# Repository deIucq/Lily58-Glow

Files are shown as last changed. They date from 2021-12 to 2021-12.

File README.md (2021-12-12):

# Lily58 - χ
ビルドガイドは[こちら](https://github.com/deIucq/Lily58-X/blob/master/buildguide.md)

BuildGuide is [here](https://github.com/deIucq/Lily58-X/blob/master/buildguide.md)

Lily58-χ(カイ)はLily58からforkされた[Lily58-glow](https://github.com/qtkb/Lily58-Glow)に以下の変更を加えたものです。
検索性向上のために，ここ以外ではLily58-Xと表記します。

- RGBLEDのpad配置をSK6812mini-e用に変更
- Underglow用LEDの場所・数を変更
- BLE Micro Proのインジケータ用にLEDを追加
- トラックパッド用のピンヘッダ・ネジ穴を追加
- 縁を覆うようなケースを追加
- I2Cと単線シリアルをスイッチできるようにジャンパーを追加
- TRRSジャックのピンアサインを変更(moduloと同様のピンアサイン)

Lily58-χ(chi) is a forked version of [Lily58-glow](https://github.com/qtkb/Lily58-Glow) from Lily58 with the following changes.

- Change RGB LED pad to SK6812mini-e's one.
- Change place and number of LEDs for underglow.
- Add LED for BLE Micro Pro's indicator.
- Add new Pinheader for trackpad modules.
- Add case that can cover edge.
- Add jumber for switching I2C and Serial
- Change TRRS pin assign

このプロジェクトは開発中です。PCBの設計にミスがある可能性があります。
This project is still in progress. There may be some mistakes in PCB design.

PCB view

# Parts

| Part Name | Quantity |
| --- | --- |
| PCB | 2 |
| Top Case,Mid Case,Bottom Case(t2 acrylic) | 2 |
| Pro Micro or BLE Micro Pro | 2 |
| Choc Key Switch | 58 |
| Keycap | 58 |
| SK6812-MINI-E | 58 |
| OLED | 2 |
| Diode 1N4148W | 58 |
| Tact switch | 2 |
| TRRS jack (option for Pro Micro) | 2 |
| TRRS cable (opton for Pro Micro) | 1 |
| M2 screw 10mm | 10 |
| M2 Nut | 20 |
| M2 spacer 10mm | 4 |
| M2 screw 4mm | 8 |
| Urethane cushion | 10 |
| Low profile pin header(1×4 & 1×6) | 2 |
| [option] RKJXY1000006 trackpad with DIP convertPCB | 1 |
| [option] 1608 LED | 1 |
| [option] Constant current diode or resistor | 1 |

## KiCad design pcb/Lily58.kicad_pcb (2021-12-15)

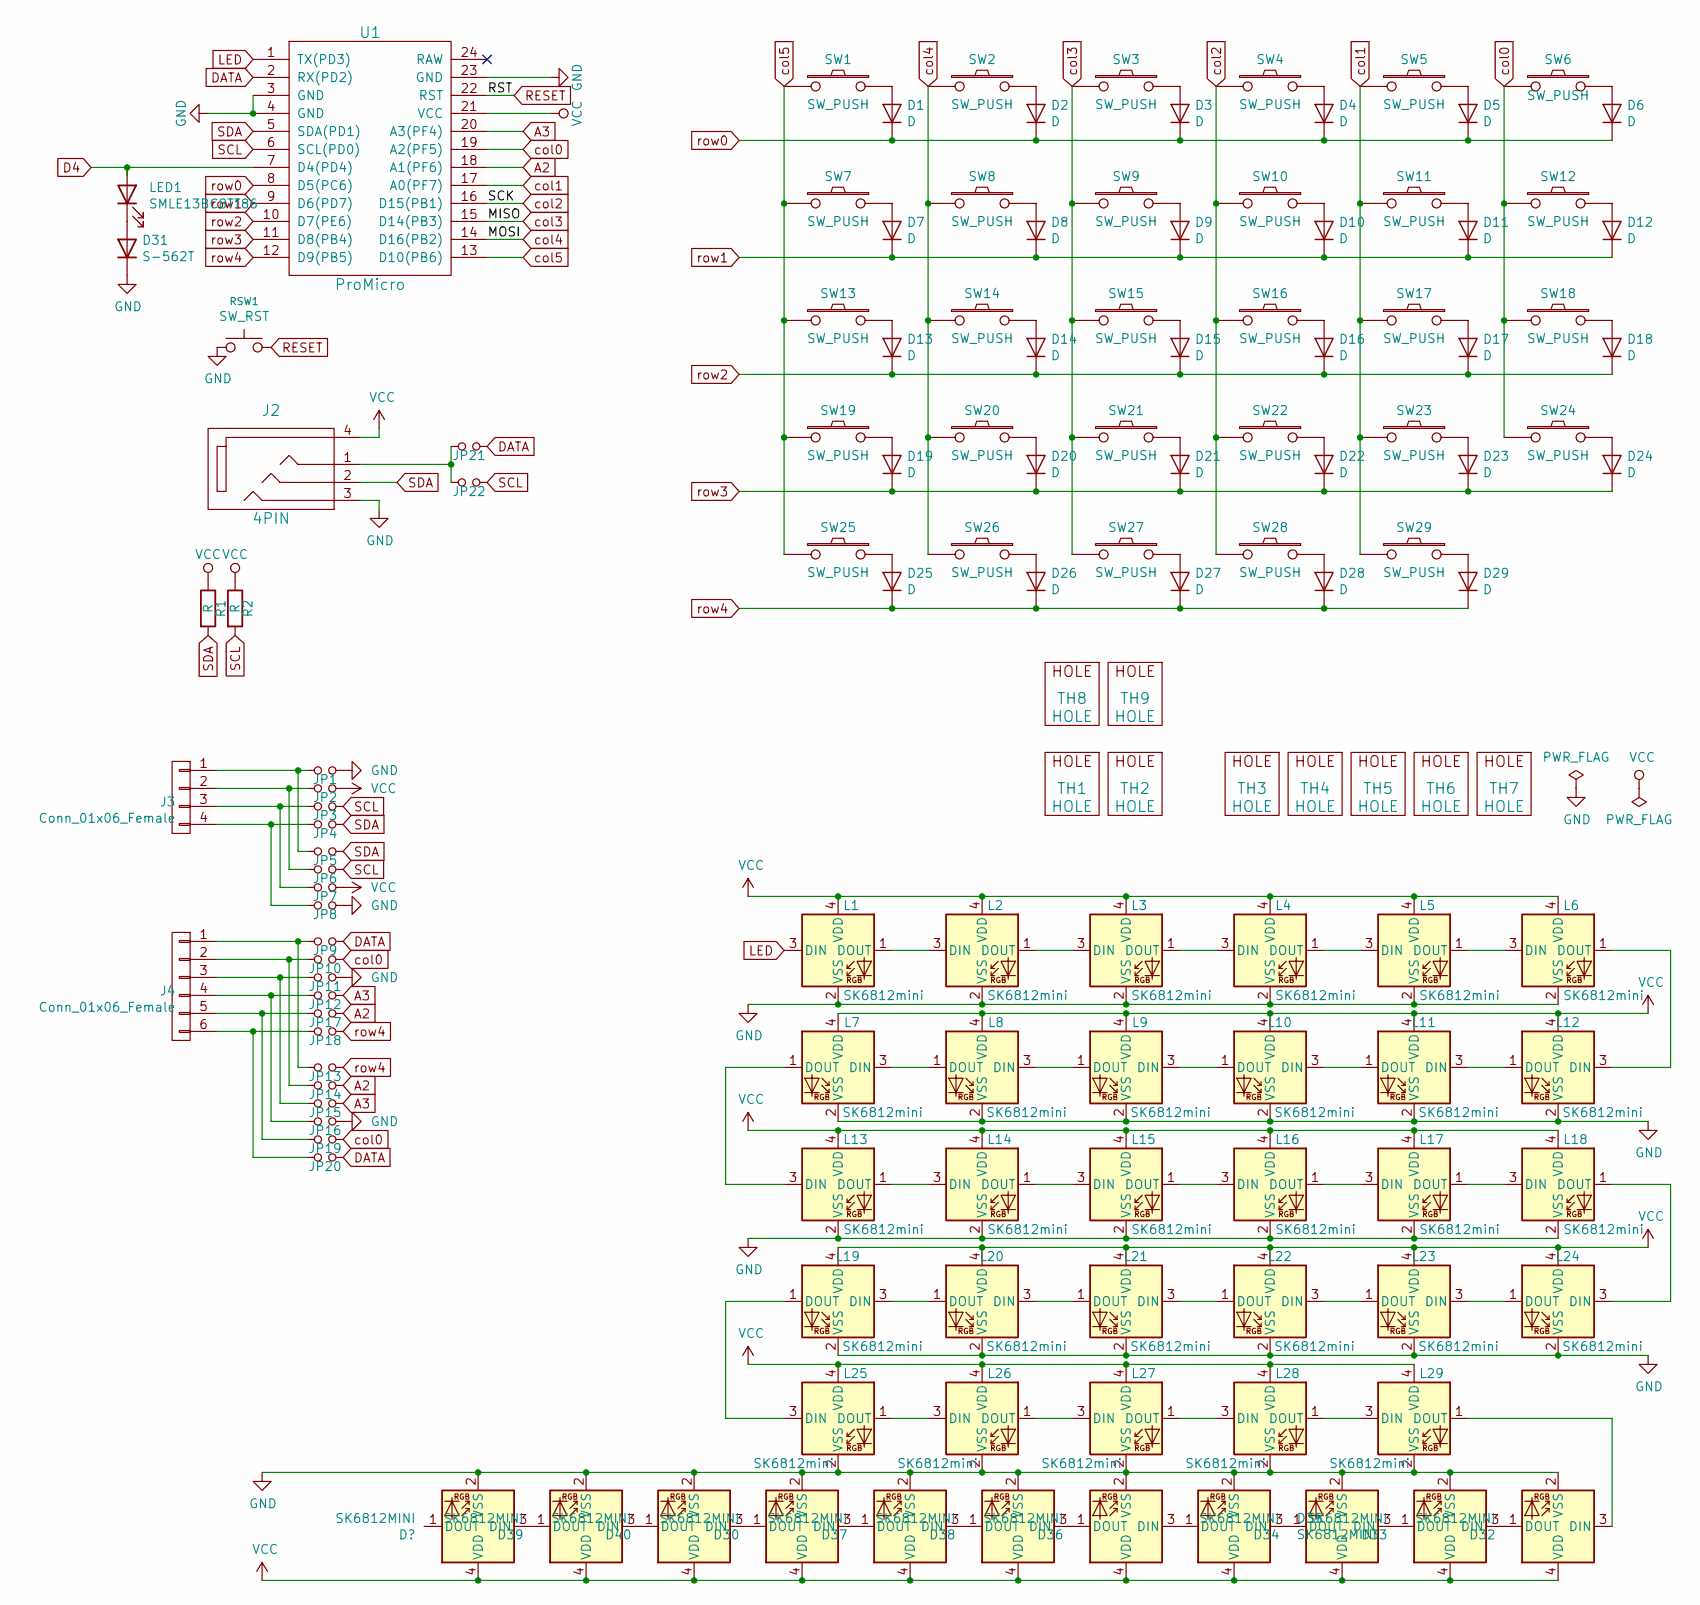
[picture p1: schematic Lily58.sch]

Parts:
D1, D2, D3, D4, D5, D6, D7, D8, D9, D10, D11, D12, D13, D14, D15, D16, D17, D18, D19, D20, D21, D22, D23, D24, D25, D26, D27, D28, D29: D; Diode_SOD123
D30, D32, D33, D34, D35, D36, D37, D38, D39, D40: SK6812MINI; SK6812MINI_underglow_rev
D31: S-562T; D_1206_3216Metric_Pad1.42x1.75mm_HandSolder
J2: 4PIN; MJ-4PP-9
J3: Conn_01x06_Female; OLED_4Pin
J4: Conn_01x06_Female; OLED_6Pin
JP1, JP2, JP3, JP4, JP5, JP6, JP7, JP8, JP9, JP10, JP11, JP12, JP13, JP14, JP15, JP16, JP17, JP18, JP19, JP20: Jumper_NO_Small; Jumper
JP21: 1S; Jumper
JP22: I2C; Jumper
L1, L2, L3, L4, L5, L6, L7, L8, L9, L10, L11, L12, L13, L14, L15, L16, L17, L18, L19, L20, L21, L22, L23, L24, L25, L26, L27, L28, L29: SK6812mini; SK6812MINI_rev
LED1: SMLE13BC8TT86; LED_0603_1608Metric_Pad1.05x0.95mm_HandSolder
R1, R2: R; RESISTOR_mini
RSW1: SW_RST; TACT_SWITCH_TVBP06
SW1, SW2, SW3, SW4, SW5, SW6, SW7, SW8, SW9, SW10, SW11, SW12, SW13, SW14, SW15, SW16, SW17, SW18, SW19, SW20, SW21, SW22, SW23, SW24, SW25, SW27, SW28, SW29: SW_PUSH; MX_PG1350_FLIP_HOLES_18mm
SW26: SW_PUSH; MX_PG1350_FLIP_HOLES_27mm
TH1, TH2, TH8, TH9: HOLE; HOLE_M2
TH3, TH4, TH5, TH6, TH7: HOLE; HOLE_M2_TH
U1: ProMicro; ProMicro_rev2

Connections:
A2: JP14.2, JP17.2, U1.18 (A1(PF6))
A3: JP12.2, JP15.2, U1.20 (A3(PF4))
D4: LED1.2 (A), U1.7 (D4(PD4))
DATA: JP9.2, JP20.2, JP21.2, U1.2 (RX(PD2))
GND: D30.2 (VSS), D31.1 (K), D32.2 (VSS), D33.2 (VSS), D34.2 (VSS), D35.2 (VSS), D36.2 (VSS), D37.2 (VSS), D38.2 (VSS), D39.2 (VSS), D40.2 (VSS), J2.3, JP1.2, JP8.2, JP11.2, JP16.2, L1.2 (VSS), L2.2 (VSS), L3.2 (VSS), L4.2 (VSS), L5.2 (VSS), L6.2 (VSS), L7.2 (VSS), L8.2 (VSS), L9.2 (VSS), L10.2 (VSS), L11.2 (VSS), L12.2 (VSS), L13.2 (VSS), L14.2 (VSS), L15.2 (VSS), L16.2 (VSS), L17.2 (VSS), L18.2 (VSS), L19.2 (VSS), L20.2 (VSS), L21.2 (VSS), L22.2 (VSS), L23.2 (VSS), L24.2 (VSS), L25.2 (VSS), L26.2 (VSS), L27.2 (VSS), L28.2 (VSS), L29.2 (VSS), RSW1.1, U1.3 (GND), U1.4 (GND), U1.23 (GND); also elsewhere on the board
LED: L1.3 (DIN), U1.1 (TX(PD3))
unnamed: D1.2 (A), SW1.2
unnamed: D2.2 (A), SW2.2
unnamed: D3.2 (A), SW3.2
unnamed: D4.2 (A), SW4.2
unnamed: D5.2 (A), SW5.2
unnamed: D6.2 (A), SW6.2
unnamed: D7.2 (A), SW7.2
unnamed: D8.2 (A), SW8.2
unnamed: D9.2 (A), SW9.2
unnamed: D10.2 (A), SW10.2
unnamed: D11.2 (A), SW11.2
unnamed: D12.2 (A), SW12.2
unnamed: D13.2 (A), SW13.2
unnamed: D14.2 (A), SW14.2
unnamed: D15.2 (A), SW15.2
unnamed: D16.2 (A), SW16.2
unnamed: D17.2 (A), SW17.2
unnamed: D18.2 (A), SW18.2
unnamed: D19.2 (A), SW19.2
unnamed: D20.2 (A), SW20.2
unnamed: D21.2 (A), SW21.2
unnamed: D22.2 (A), SW22.2
unnamed: D23.2 (A), SW23.2
unnamed: D24.2 (A), SW24.2
unnamed: D25.2 (A), SW25.2
unnamed: D26.2 (A), SW26.2
unnamed: D27.2 (A), SW27.2
unnamed: D28.2 (A), SW28.2
unnamed: D29.2 (A), SW29.2
unnamed: D30.1 (DOUT), D40.3 (DIN)
unnamed: D30.3 (DIN), D37.1 (DOUT)
unnamed: D31.2 (A), LED1.1 (K)
unnamed: D32.1 (DOUT), D33.3 (DIN)
unnamed: D32.3 (DIN), L29.1 (DOUT)
unnamed: D33.1 (DOUT), D34.3 (DIN)
unnamed: D34.1 (DOUT), D35.3 (DIN)
unnamed: D35.1 (DOUT), D36.3 (DIN)
unnamed: D36.1 (DOUT), D38.3 (DIN)
unnamed: D37.3 (DIN), D38.1 (DOUT)
unnamed 45: D39.1 (DOUT); also elsewhere on the board
unnamed: D39.3 (DIN), D40.1 (DOUT)
unnamed: J2.1, JP21.1, JP22.1
unnamed: J3.1, JP1.1, JP5.1
unnamed: J3.2, JP2.1, JP6.1
unnamed: J3.3, JP3.1, JP7.1
unnamed: J3.4, JP4.1, JP8.1
unnamed: J4.1, JP9.1, JP13.1
unnamed: J4.2, JP10.1, JP14.1
unnamed: J4.3, JP11.1, JP15.1
unnamed: J4.4, JP12.1, JP16.1
unnamed: J4.5, JP17.1, JP19.1
unnamed: J4.6, JP18.1, JP20.1
unnamed: L1.1 (DOUT), L2.3 (DIN)
unnamed: L2.1 (DOUT), L3.3 (DIN)
unnamed: L3.1 (DOUT), L4.3 (DIN)
unnamed: L4.1 (DOUT), L5.3 (DIN)
unnamed: L5.1 (DOUT), L6.3 (DIN)
unnamed: L7.3 (DIN), L8.1 (DOUT)
unnamed: L8.3 (DIN), L9.1 (DOUT)
unnamed: L9.3 (DIN), L10.1 (DOUT)
unnamed: L10.3 (DIN), L11.1 (DOUT)
unnamed: L11.3 (DIN), L12.1 (DOUT)
unnamed: L6.1 (DOUT), L12.3 (DIN)
unnamed: L13.1 (DOUT), L14.3 (DIN)
unnamed: L7.1 (DOUT), L13.3 (DIN)
unnamed: L14.1 (DOUT), L15.3 (DIN)
unnamed: L15.1 (DOUT), L16.3 (DIN)
unnamed: L16.1 (DOUT), L17.3 (DIN)
unnamed: L17.1 (DOUT), L18.3 (DIN)
unnamed: L18.1 (DOUT), L24.3 (DIN)
unnamed: L19.1 (DOUT), L25.3 (DIN)
unnamed: L19.3 (DIN), L20.1 (DOUT)
unnamed: L20.3 (DIN), L21.1 (DOUT)
unnamed: L21.3 (DIN), L22.1 (DOUT)
unnamed: L22.3 (DIN), L23.1 (DOUT)
unnamed: L23.3 (DIN), L24.1 (DOUT)
unnamed: L25.1 (DOUT), L26.3 (DIN)
unnamed: L26.1 (DOUT), L27.3 (DIN)
unnamed: L27.1 (DOUT), L28.3 (DIN)
unnamed: L28.1 (DOUT), L29.3 (DIN)
RESET: RSW1.2, U1.22 (RST)
SCL: JP3.2, JP6.2, JP22.2, R2.2, U1.6 (SCL(PD0))
SDA: J2.2, JP4.2, JP5.2, R1.2, U1.5 (SDA(PD1))
VCC: D30.4 (VDD), D32.4 (VDD), D33.4 (VDD), D34.4 (VDD), D35.4 (VDD), D36.4 (VDD), D37.4 (VDD), D38.4 (VDD), D39.4 (VDD), D40.4 (VDD), J2.4, JP2.2, JP7.2, L1.4 (VDD), L2.4 (VDD), L3.4 (VDD), L4.4 (VDD), L5.4 (VDD), L6.4 (VDD), L7.4 (VDD), L8.4 (VDD), L9.4 (VDD), L10.4 (VDD), L11.4 (VDD), L12.4 (VDD), L13.4 (VDD), L14.4 (VDD), L15.4 (VDD), L16.4 (VDD), L17.4 (VDD), L18.4 (VDD), L19.4 (VDD), L20.4 (VDD), L21.4 (VDD), L22.4 (VDD), L23.4 (VDD), L24.4 (VDD), L25.4 (VDD), L26.4 (VDD), L27.4 (VDD), L28.4 (VDD), L29.4 (VDD), R1.1, R2.1, U1.21 (VCC); also elsewhere on the board
col0: JP10.2, JP19.2, SW6.1, SW12.1, SW18.1, SW24.1, U1.19 (A2(PF5))
col1: SW5.1, SW11.1, SW17.1, SW23.1, SW29.1, U1.17 (A0(PF7))
col2: SW4.1, SW10.1, SW16.1, SW22.1, SW28.1, U1.16 (D15(PB1))
col3: SW3.1, SW9.1, SW15.1, SW21.1, SW27.1, U1.15 (D14(PB3))
col4: SW2.1, SW8.1, SW14.1, SW20.1, SW26.1, U1.14 (D16(PB2))
col5: SW1.1, SW7.1, SW13.1, SW19.1, SW25.1, U1.13 (D10(PB6))
row0: D1.1 (K), D2.1 (K), D3.1 (K), D4.1 (K), D5.1 (K), D6.1 (K), U1.8 (D5(PC6))
row1: D7.1 (K), D8.1 (K), D9.1 (K), D10.1 (K), D11.1 (K), D12.1 (K), U1.9 (D6(PD7))
row2: D13.1 (K), D14.1 (K), D15.1 (K), D16.1 (K), D17.1 (K), D18.1 (K), U1.10 (D7(PE6))
row3: D19.1 (K), D20.1 (K), D21.1 (K), D22.1 (K), D23.1 (K), D24.1 (K), U1.11 (D8(PB4))
row4: D25.1 (K), D26.1 (K), D27.1 (K), D28.1 (K), D29.1 (K), JP13.2, JP18.2, U1.12 (D9(PB5))

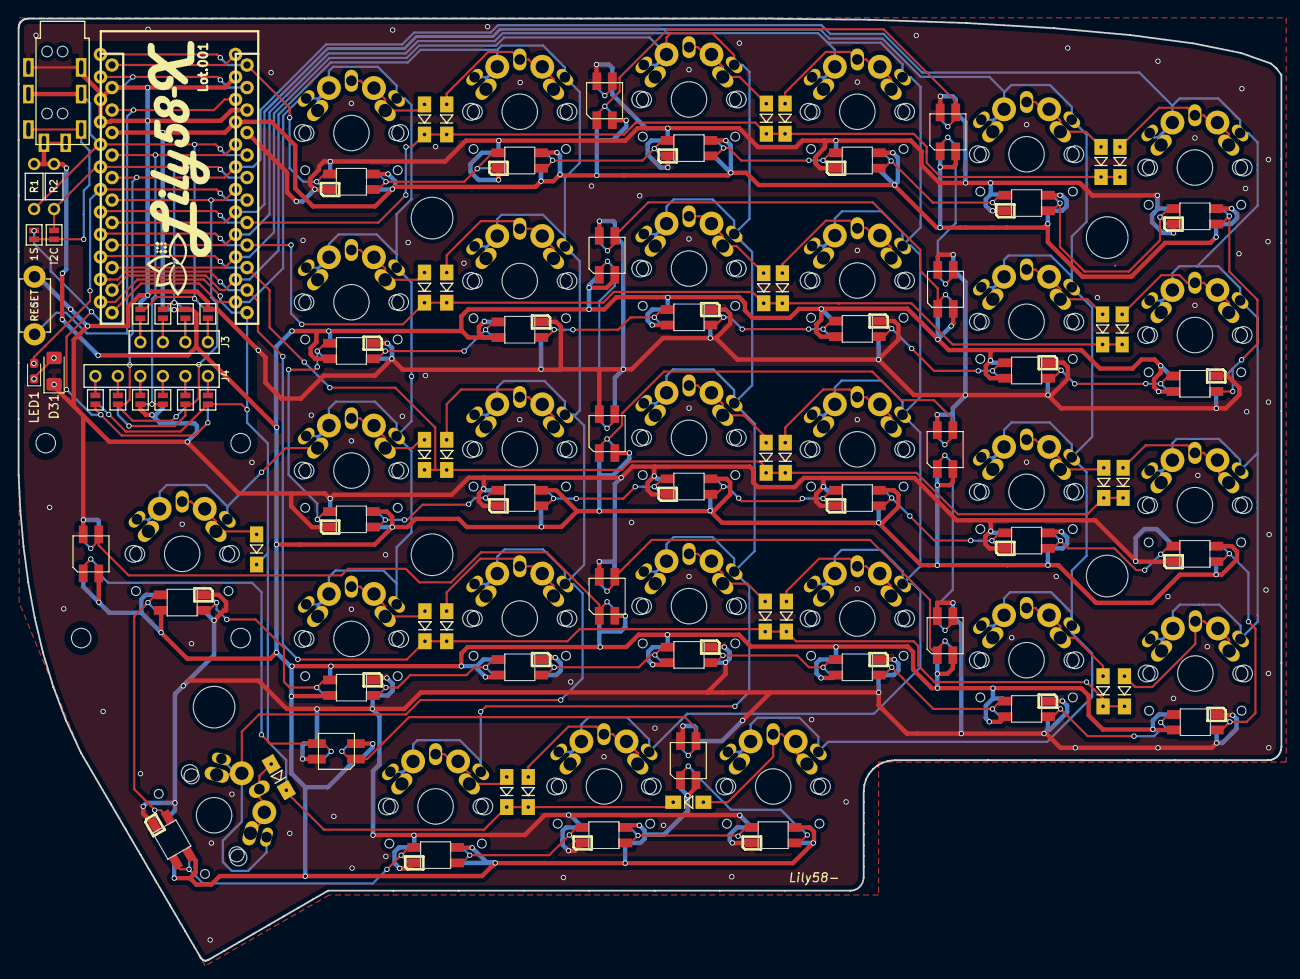
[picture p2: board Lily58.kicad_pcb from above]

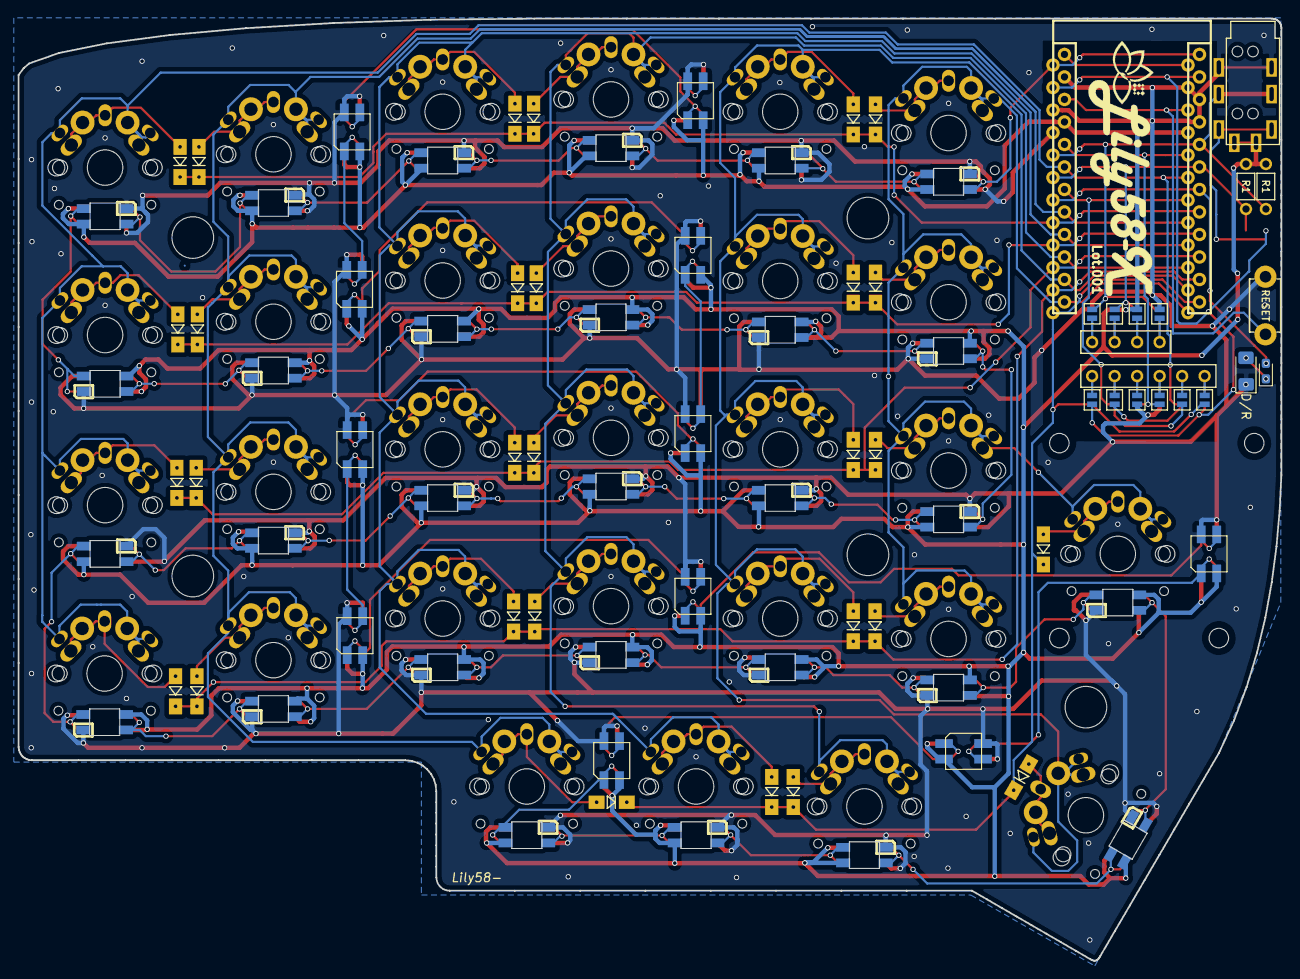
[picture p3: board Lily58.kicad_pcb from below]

Board: 2 copper layers, 142.5 x 106.3 mm, 138 parts (38 on the bottom side), 101 nets.

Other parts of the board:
D41: SK6812MINI; SK6812MINI_underglow_rev

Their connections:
GND: D41.2; also elsewhere on the board
unnamed 45: D41.3; also elsewhere on the board
VCC: D41.4; also elsewhere on the board

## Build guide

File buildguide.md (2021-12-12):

# Lily58-X ビルドガイド

## パーツ

| パーツ名 | 個数 | 備考 |
| --- | ---- | --- |
| Lily58-X キット | 1 | PCB，ケース，RGBLED，ダイオード，ピンソケット，タクトスイッチ，TRRSジャック，ネジ類，ゴム足が付属しています |
| Pro Micro or BLE Micro Pro | 2 | BLE Micro Proは複雑なので初めての方はPro Microを推奨します。<br>また，コネクタが破損したときなどにボードを交換できるようにコンスルーの使用を推奨します。 |
| キースイッチ | 58 | ChocでもMXでも可。ただし，MXの場合はミッドプレートとトッププレートの間に隙間が空き，完全に縁が埋まりません。ChocのためのケースなのでChocを推奨します。 |
| キーキャップ | 58 | ネジの突き出しがあるので，スイッチ取り付け部より下に張り出すキーキャップ(例:kailh公式transparentキーキャップ)を使うとネジに少し当たります。Chocolate形のみ大丈夫であることを確認しています。 |
| TRRSケーブル | 1 | 単線シリアル(後述)にする場合はTRSケーブルでも可 |
| USBケーブル | 1 | 使うボードに合わせて選んでください。(Pro Microの場合はMicro USB，BLE Micro Proの場合はType C) |
| [Option] Underglow用 SK6812MINI | 5 | はんだ付けが難しい・スペース的にギリギリなことからオプションとしています。 |
| [Option] 1608サイズLED・定電流ダイオード | 1 | BLE Micro Proのインジケータ用のLEDを取り付けることができます。パーツが小さく，はんだ付けが難しいので上級者向けかもしれません。<br />[LED](https://akizukidenshi.com/catalog/g/gI-15109/)[定電流ダイオード](https://akizukidenshi.com/catalog/g/gI-06282/) |
| [Option] トラックパッド | 0~1  | トラックパッドを使う場合は，キースイッチ・キーキャップは57個となります。 |
| [Option] OLED | 0~2  | BLE Micro Proとはバッテリーのスペースの問題で共存できません。 |

## 工具

- ドライバー
- はんだ付けに使う道具類
  - はんだごて
  - はんだ
  - ピンセット(推奨)
  - ハンダ吸い取り線またはハンダ吸い取り器(失敗したときの修正に必要)
  - マスキングテープ(あると良い)
  - フラックス(あると良い。はんだ付けする前に金属部分に塗ります。)

## 

## 

## オプション

このキーボードにはいくつかのオプションがあります。排他的であるものが多いので注意してください。

- ジョイスティック
  秋月のRKJXY1000006 DIP化キットを直差ししてポインティングデバイス(=マウス)として利用することができます。
  https://akizukidenshi.com/catalog/g/gK-15425/
- 左右の通信方式
  I2Cと単線シリアルの2種類から選べます。
  I2Cはジョイスティックを使う場合・BLE Micro Proと組み合わせて半無線化するモジュールであるLPME-IOを使う場合に選択してください。
  単線シリアルの場合は，TRRSではなくTRSケーブルで通信できるというメリットがあります。

## 手順

0. [基板の左右を決める](#基板の左右を決める)
1. [ダイオード・RGBLED取り付け](#ダイオード・RGBLED取り付け)
2. [インジケータ用ダイオード・LED取り付け](#インジケータ用ダイオード・LED取り付け)
3. [TRRSジャック・リセットスイッチ・ピンソケット取り付け](#TRRSジャック・リセットスイッチ・ピンソケット取り付け)
4. [ジャンパ](#ジャンパ)
5. [Pro Micro / BLE Micro Pro取り付け](#Pro Micro / BLE Micro Pro取り付け)
6. [トッププレートとキースイッチ取り付け](#トッププレートとキースイッチ取り付け)
7. [基板洗浄](#基板洗浄])
8. [トラックパッド取り付け](#トラックパッド取り付け)
9. [スペーサー取り付け](#スペーサー取り付け)
10. [OLED取り付け](#OLED取り付け)
11. [ミッドプレート・ボトムプレート・ゴム足取り付け](#ミッドプレート・ボトムプレート・ゴム足取り付け)
10. [ファームウェア書き込み](#ファームウェア書き込み)

## 基板の左右を決める

Lily58-Xの基板はリバーシブルになっています。つまり，右側の基板を二枚作ってしまったというようなミスが起こる可能性があるので，まずはどちらの基板を左/右にするか決めて，表面がどちらなのかそれぞれ覚えておきましょう。(不安な場合は，マスキングテープなどで印を付けておくことをおすすめします。)

## ダイオード・RGBLED取り付け

ダイオードとLEDは基板の**裏面**に取り付けます。

ダイオードは線が引いてあるほうがカソードです。基板上の矢印のようなダイオードの記号の向きに合わせてはんだ付けします。
表面実装の部品は先にパッドを1つだけ予備ハンダして，それを使って固定してから他のパッドをはんだ付けするとやりやすいです。

LEDはLED側は端が欠けている様な形をしているピン，基板側は黒い線で囲われているパッドがGNDになっています。それぞれ合わせてはんだ付けします。
LEDの裏表は表面の方が光るようにします。(GNDをあわせていれば間違えようがないですが)間違えないようにしましょう。

## インジケータ用ダイオード・LED取り付け

基本的にBLE Pro Micro向けなのでPro Microのみを用いる場合は飛ばしても良いです。

表面実装のダイオードとLEDを取り付けます。
極性は基板上で黒い線が引かれている側がカソードで，ダイオードは線が引かれている方，LEDは裏面を見て矢印が向いている方がカソードです。それぞれ合わせてはんだ付けします。

## TRRSジャック・リセットスイッチ・ピンソケット取り付け

TRRSジャック，リセットスイッチ，ピンヘッダは表側から挿してマスキングテープなどで仮固定し，裏面からはんだ付けします。

## ジャンパ

ピンヘッダ近くの**表側**のパッドをジャンパさせてください。
また，左右の通信方式に合わせてパッドをジャンパさせてください。(これは片面にしか有りません。)

## Pro Micro / BLE Micro Pro取り付け

取り付け位置はそれぞれ表面から見て黒い枠で囲まれている部分に表面から取り付けます。

Pro Micro，BLE Micro Pro共に，**マイコンなどの部品が載っている側が下になるように**取り付けます。
Arduino Nanoなどとは違う方向なので注意してください。

### コンスルーを使う場合

Helixの[ビルドガイド](https://github.com/MakotoKurauchi/helix/blob/master/Doc/buildguide_jp.md#pro-micro)を参考にしてはんだ付けを行います。

Pro Microの場合はPro Micro側のみはんだ付けを行い、PCB側ははんだ付けしません。
BLE Micro Proの場合はどちらもはんだ付けの必要はありません。

はんだ付けが終わった後は浮きが無いようにしっかりと差し込みます。

### 通常のピンヘッダを使う場合

先にピンヘッダを差し込み，その上にPro Microを載せてはんだ付けします。
その後，マスキングテープなどで仮固定し，裏面からピンヘッダをはんだ付けします。

## トッププレートとキースイッチ取り付け

トッププレートはジョイスティックが使えるものと使えないものがあります。**どちらにジョイスティックを取り付けるか確認**した後，

トッププレートの4つ角にキースイッチを取り付けて

- キースイッチがPCBから浮いていないこと
- ピンが曲がっていないこと
をよく確認してはんだ付けします。

その後，トッププレートに残りのスイッチを取り付けてピンがしっかり通っていることを確認してはんだ付けします。
スイッチのピンの足が曲がってしまった際は，手でもとに戻してください。

## 基板洗浄

ここではんだ付けは終了です。お疲れさまでした。
はんだ付けをした後，基板にフラックスによる茶色っぽい色の汚れが付着していると思います。放置しても基本的には問題ないと思いますが，見栄えがよろしくないので可能であればエタノールやIPAといったアルコール系の溶剤と綿棒などを使ってフラックスの洗浄をしましょう。

## ジョイスティック取り付け

ジョイスティックを取り付ける場合はこの段階で取り付けます。
ジョイスティックと基板のネジ穴を合わせてネジで固定します。

## スペーサー取り付け

保護パネル用のスペーサーを取り付けます

## OLED取り付け

OLEDを取り付ける場合はこの段階で取り付けます。

## ミッドプレート・ボトムプレート・ゴム足取り付け

ミッドプレートとボトムプレートの位置を合わせてネジ止めして裏面にゴム足を取り付けます。

## ファームウェア書き込み

### Pro Microの場合

- VIAを使う

  1. Githubにあるhexファイルとjsonファイルをダウンロード

  2. Pro Micro Web UpdaterもしくはQMK ToolBoxを使ってhexファイルを書き込む
     参考：
     [（初心者編）自作キーボードにファームウェアを書き込む](https://salicylic-acid3.hatenablog.com/entry/qmk-toolbox)
     
  3. [VIA](https://github.com/the-via/releases/releases/tag/v1.3.1)もしくは[Remap](https://remap-keys.app/)を使ってキーマップを変更
     参考：[（初心者編）VIAを使ってキーマップを書き換えよう](https://salicylic-acid3.hatenablog.com/entry/via-manual)，[（初心者編）Remapを使ってキーマップを書き換えよう](https://salicylic-acid3.hatenablog.com/entry/remap-manual)
     
  3. ただし，jsonファイルをVIAやRemapに登録していないため，
     
     - VIAの場合SETTINGS→Show Design tabを有効→DESIGNタブに先ほどダウンロードしたjsonファイルをドラッグアンドドロップ
     - Remapの場合，キーボードを選択した後の"Please import your **Lily58-X** definition file(.json)."という画面で先ほどダウンロードしたjsonファイルをドラッグアンドドロップ
     
     という工程を踏んでください。
     (たくさん売れたらVIA/Remapにプルリクエストを出します。すいません...)

- 自分でファームウェアをビルドする(上級者向け)

  QMKの環境構築やビルド方法などは省略します。

### BLE Pro Microの場合

- デフォルトのuf2を使う
  0. Bootloaderをアップデートする
     参考：
  1. Githubにあるuf2ファイルとconfigファイルをダウンロード
  2. リセットボタン長押しでdfuを呼び出してuf2ファイルを外部ストレージとして認識されたBLEPROMICROにコピーしてインストール
  3. configファイルをインストール
- 自分でファームウェアをビルドする(かなり上級者向け)
  Github

完成です。お疲れ様でした。

## 開発者向け情報

- ピンアサイン

  | PIN  | AVR(Pro Micro) | nrf52(BLE Micro Pro) | 内容(Pro Micro/BLE Micro Pro)   |
  | ---- | -------------- | -------------------- | ------------------------------- |
  | 1    | D3             | P0.8                 | LED (SK6812MINI-E)              |
  | 2    | D2             | P0.11                | DATA (左右間の独自シリアル通信) |
  | 3    | -              | -                    | GND                             |
  | 4    | -              | -                    | GND                             |
  | 5    | D1             | P0.18                | I2C(SDA)                        |
  | 6    | D0             | P0.16                | I2C(SCL)                        |
  | 7    | D4             | P0.19                | LED(インジケータ)               |
  | 8    | C6             | P0.20                | row0                            |
  | 9    | D7             | P0.22                | row1                            |
  | 10   | E6             | P0.23                | row2                            |
  | 11   | B4             | P1.0                 | row3                            |
  | 12   | B5             | P1.3                 | row4                            |
  | 13   | B6             | P0.9                 | col5                            |
  | 14   | B2             | P0.10                | col4                            |
  | 15   | B3             | P1.15                | col3                            |
  | 16   | B1             | P1.14                | col2                            |
  | 17   | F7             | P0.3 (AIN 1)         | col1                            |
  | 18   | F6             | P0.30 (AIN 6)        | **A6** / J2                     |
  | 19   | F5             | P0.0                 | **col0 **/ J3                   |
  | 20   | F4             | P0.5 (AIN3)          | **A3**                          |
  | 21   | -              | -                    | VCC/+4.3V                       |
  | 22   | -              | -                    | BOOT/RESET                      |
  | 23   | -              | -                    | GND                             |
  | 24   | -              | -                    | RAW/+5V                         |

  特に，BLE Pro MicroでのADCを使うためにcol0が18ピンから19ピンに移されていることに注意してください。Lily58のファームウェアなどを使う際には，ピンアサインを変更する必要があります。
  
  また，6ピンのピンヘッダの内訳は，左からrow4/A2/col0/GND/A3/DATAです。
  
  BLE Pro Microに搭載されているnrf52840にはもちろんもっと多くのADCポートがありますが，現状使えるのは17,18,20ピンのみのようです。

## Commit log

2021-11-14 add LED for BLE Micro Pro indicator
    [Lily58.kicad_pcb, Lily58.sch]
2021-11-14 add diode and LED footprint for lily58
2021-11-14 changed oled footprint(4pin -> 6pin)
2021-11-14 change pinsocket 4pin -> 6pin
    [Lily58.kicad_pcb, Lily58.sch]
2021-11-15 add pcb pic
2021-11-15 changed LED pad for SK6812MINI-E
    [Lily58.kicad_pcb]
2021-11-15 copy lily58 case
2021-11-15 change pad and delete underglow
    [Lily58.kicad_pcb, Lily58.sch]
2021-11-16 add pinheader and logo
    [Lily58.kicad_pcb, Lily58.sch]
2021-11-16 add via
    [Lily58.kicad_pcb]
2021-11-17 brush up PCB
    [Lily58.kicad_pcb, Lily58.sch]
2021-11-17 add gerber
    [Lily58.GBL, Lily58.GBO, Lily58.GBS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]
2021-11-17 add large case
2021-11-20 update pcb pic
2021-11-20 udpate case
2021-12-01 change case
2021-12-02 add sk6812mini
    [Lily58.kicad_pcb, Lily58.sch]
2021-12-02 update sk6812mini pin assgin
    [Lily58.kicad_pcb, Lily58.sch]
2021-12-02 change 3.5mm jack assign
    [Lily58.kicad_pcb, Lily58.sch]
2021-12-05 Revert "change 3.5mm jack assign"
    This reverts commit aa684eaece7f45b972ff72976500a763c7363c79.
    [Lily58.kicad_pcb, Lily58.sch]
2021-12-10 change pcb - delete underglow - change pins - change holes for sk6812mini-e
    [Lily58.kicad_pcb, Lily58.sch]
2021-12-10 change gerber place
    [Lily58.GBL, Lily58.GBO, Lily58.GBS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]
2021-12-10 config gerbers
    [Lily58.GBL, Lily58.GBO, Lily58.GBS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]
2021-12-10 update pcb
    [Lily58.kicad_pcb]
2021-12-12 add SMD only diode
2021-12-12 add underglow
    [Lily58.kicad_pcb, Lily58.sch]
2021-12-13 add 001 gerber
2021-12-14 fix joystick pinout
    [Lily58.kicad_pcb, Lily58.sch]
2021-12-15 refuctor pcb
    [Lily58.kicad_pcb, Lily58.sch]
